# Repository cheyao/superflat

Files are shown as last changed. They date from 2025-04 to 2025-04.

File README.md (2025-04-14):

# Superflat - a ultra low profile bluetooth keyboard

A super flat PG1316 bluetooth split keyboard - The thickness is projected to be within 1cm. And the dimensions will be around  12x12cm

The design has it's custom USB port, battery protection & charging circuit and bluetooth nRF52840 integration.

The firmware that will be used will be zmk, and the projected battery life will be 2 months

[](https://hc-cdn.hel1.your-objectstorage.com/s/v3/b5915856e3878978d86f16c3d9073a392f0f9930_image.png)
[](https://hc-cdn.hel1.your-objectstorage.com/s/v3/1f7b83f37460ca8510d710ef73af309514f418d7_image.png)
[](https://hc-cdn.hel1.your-objectstorage.com/s/v3/72b54a600d9b8fe1c61734ac12d110f5b7c6d3d2_image.png)
[](https://hc-cdn.hel1.your-objectstorage.com/s/v3/e2f3d3d02bae474faccb280b3d4234a8bf3ab1c3_image.png)

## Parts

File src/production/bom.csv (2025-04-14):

Designator | Footprint | Quantity | Value | LCSC Part #
C1, C7 | 0805 | 2 | 100n | C28233
C2, C3 | 0805 | 2 | 4.7u | C1779
C5, C6 | 0805 | 2 | 1u | C28323
D1, D10, D11, D12, D13, D14, D15, D16, D17, D18, D19, D2, D20, D21, D22, D23, D24, D25, D26, D27, D28, D29, D3, D30, D4, D5, D6, D7, D8, D9 | D_SOD-123F | 30 | D | C64898
D31 | D_SMA | 1 | BSD3C051V | C151996
D32 | 0805 | 1 | LED | C2297
F1 | 1206 | 1 | 750mA | C99536
J1 | USB_C_Receptacle_HRO_TYPE-C-31-M-14 | 1 | USB_C_Receptacle_USB2.0_16P | C223907
J2 | PinHeader_1x04_P2.54mm_Vertical | 1 | Conn_01x04_Pin
J3, J5 | PinHeader_1x02_P2.54mm_Vertical | 2 | Conn_01x02_Pin
J4, J6 | PinHeader_1x05_P2.54mm_Vertical | 2 | Conn_01x05_Pin
L1, L2 | 0402 | 2 | BLM15PD121SN1D
Q1, Q2 | SOT-23 | 2 | 2N7002 | C8545
R1, R2 | 0805 | 2 | 5.1k | C27834
R10, R15 | 0805 | 2 | 100k | C149504
R11 | 0603 | 1 | 2M | C22976
R12 | 0805 | 1 | 806k | C63494
R13, R8 | 0805 | 2 | 100 | C17408
R14, R6, R9 | 0805 | 3 | 10k | C17414
R3 | 0805 | 1 | 3.9k | C17614
R4, R7 | 0805 | 2 | 1.5k | C4310
R5 | 0805 | 1 | 47k | C17713
SW1, SW10, SW11, SW12, SW13, SW14, SW15, SW16, SW17, SW18, SW19, SW2, SW20, SW21, SW22, SW23, SW24, SW25, SW26, SW27, SW28, SW29, SW3, SW30, SW4, SW5, SW6, SW7, SW8, SW9 | SW_PG1316S | 30 | SW_Push
SW31, SW33 | Slide | 2 | SW_SPDT
SW32, SW34 | SolderJumper-2_P1.3mm_Open_RoundedPad1.0x1.5mm | 2 | SW_Push
U1, U5 | nRF52840_holyiot_18010_HS_simple | 2 | nRF52840_holyiot_18010
U2 | SOT-23-6-routable | 1 | SRV05-4 | C85364
U3 | VQFN-16-1EP_3x3mm_P0.5mm_EP1.6x1.6mm | 1 | BQ24075RGT | C15464
U4 | SOT-23-3 | 1 | XC6206PxxxMR

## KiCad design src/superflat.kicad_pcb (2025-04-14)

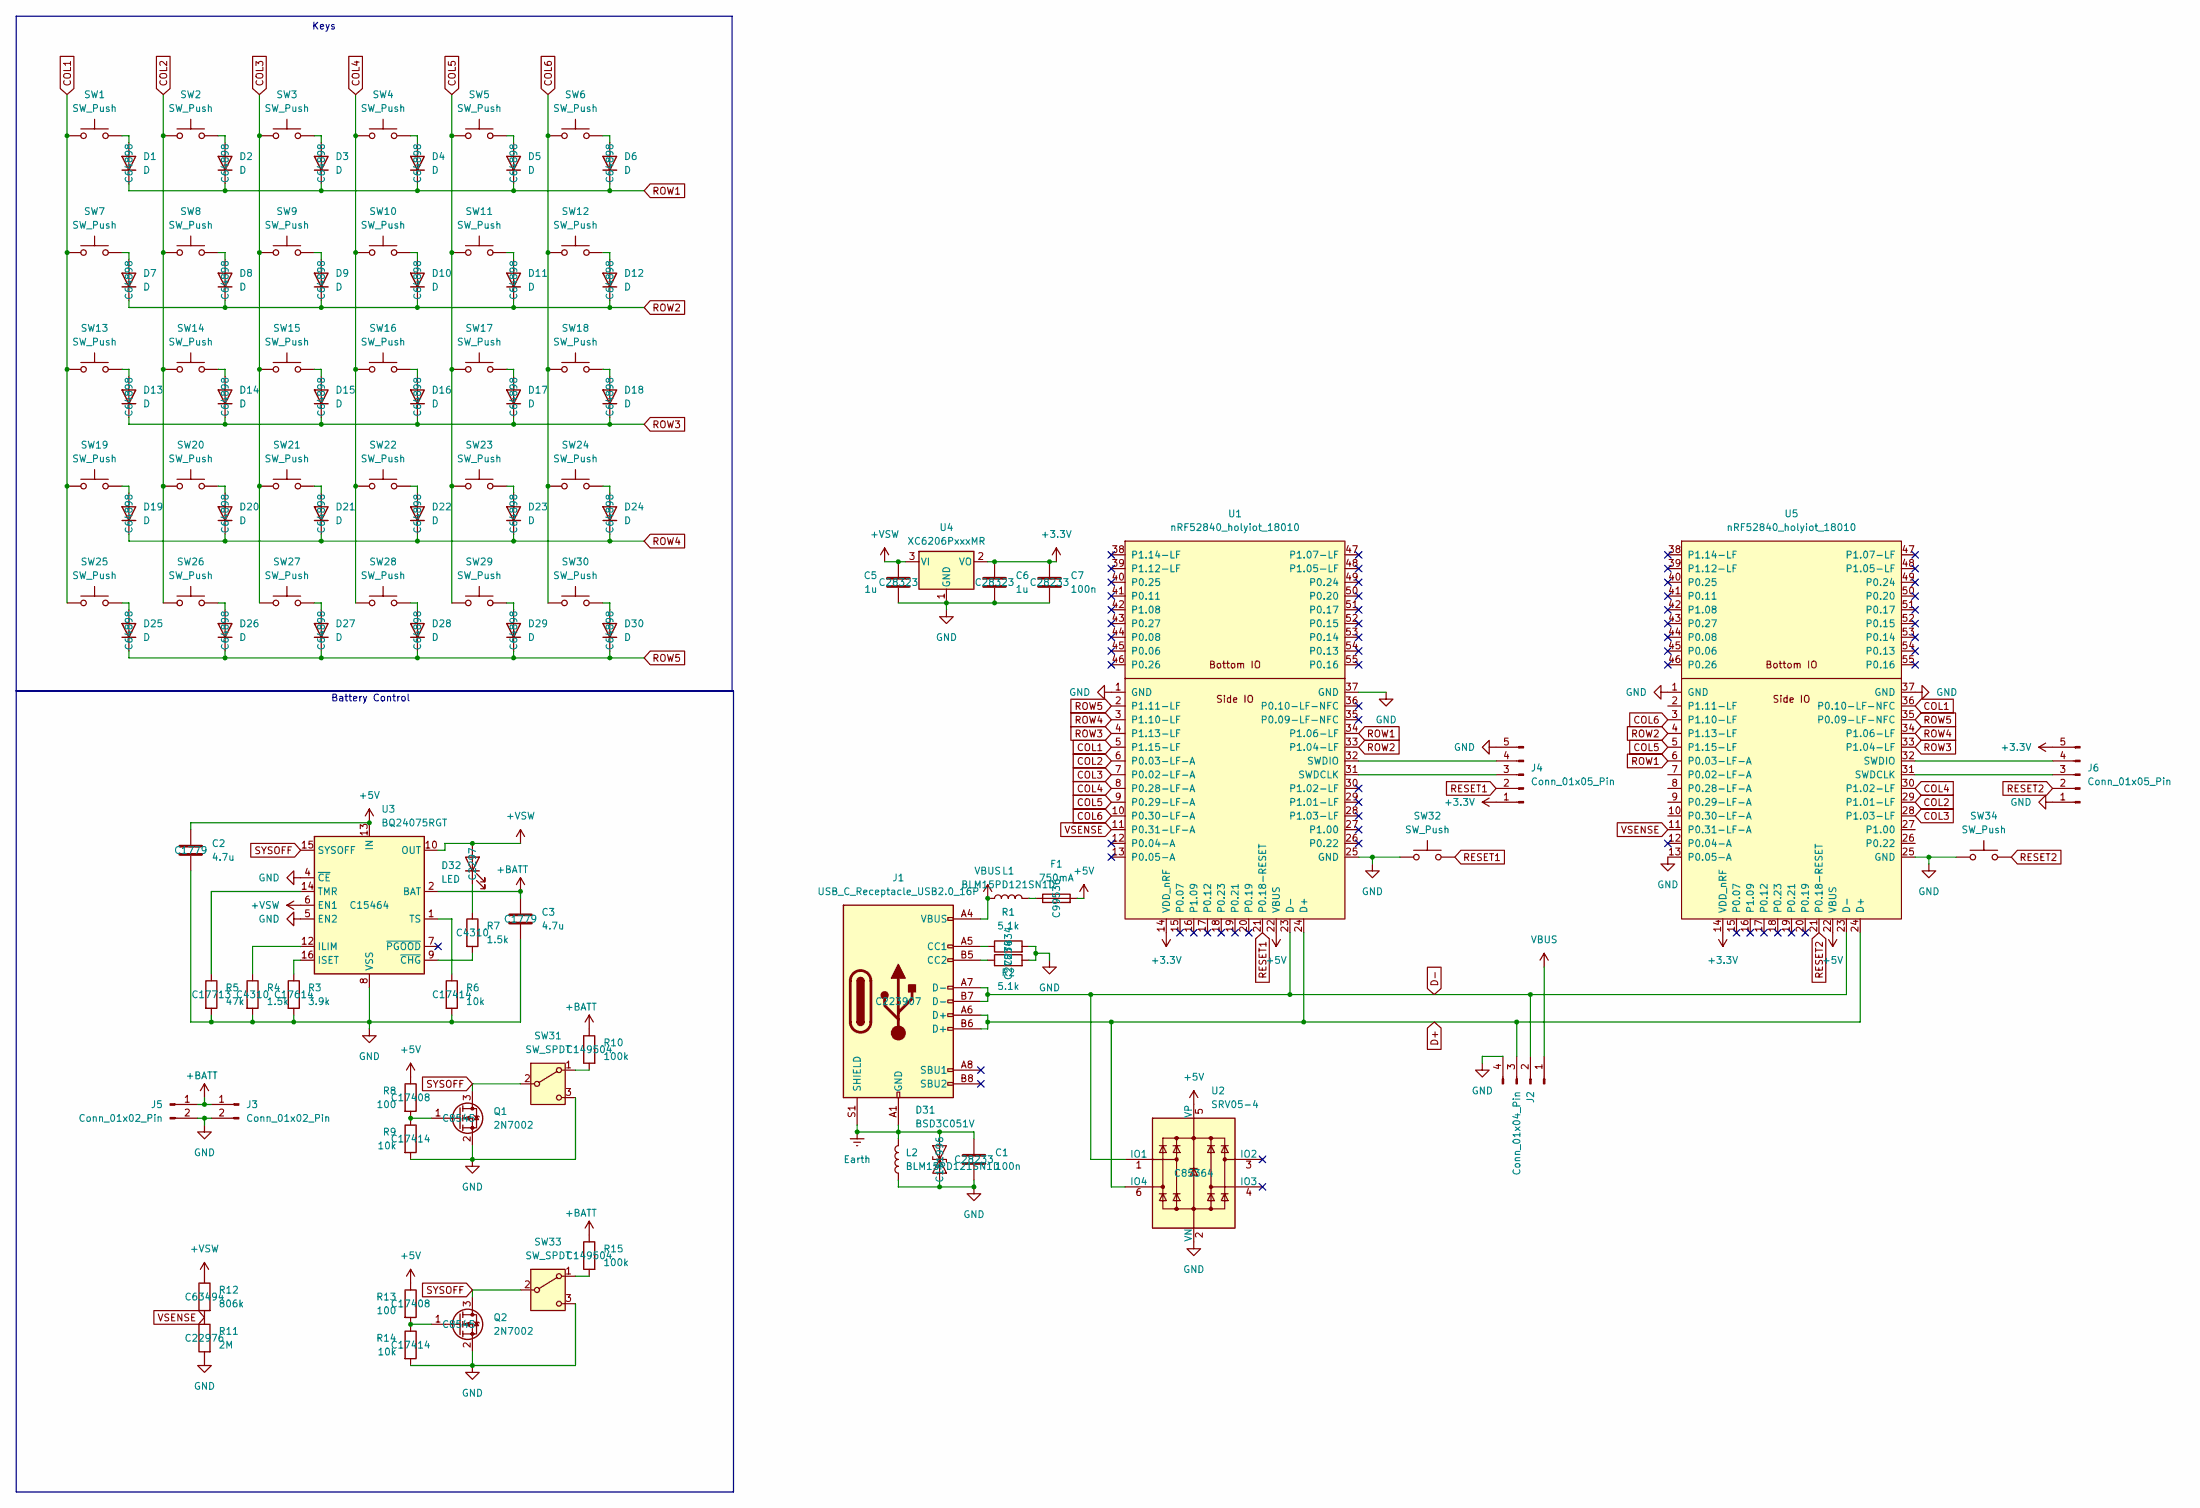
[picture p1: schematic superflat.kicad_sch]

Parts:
C1, C7: 100n; C_0805_2012Metric_Pad1.18x1.45mm_HandSolder; LCSC C28233
C2, C3: 4.7u; C_0805_2012Metric_Pad1.18x1.45mm_HandSolder; LCSC C1779
C5, C6: 1u; C_0805_2012Metric_Pad1.18x1.45mm_HandSolder; LCSC C28323
D1, D2, D3, D4, D5, D6, D7, D8, D9, D10, D11, D12, D13, D14, D15, D16, D17, D18, D19, D20, D21, D22, D23, D24, D25, D26, D27, D28, D29, D30: D; D_SOD-123F; LCSC C64898
D31: BSD3C051V; D_SMA; LCSC C151996
D32: LED; LED_0805_2012Metric_Pad1.15x1.40mm_HandSolder; LCSC C2297
F1: 750mA; Fuse_1206_3216Metric_Pad1.42x1.75mm_HandSolder; LCSC C99536
J1: USB_C_Receptacle_USB2.0_16P; USB_C_Receptacle_HRO_TYPE-C-31-M-14; LCSC C223907
J2: Conn_01x04_Pin; PinHeader_1x04_P2.54mm_Vertical
J3, J5: Conn_01x02_Pin; PinHeader_1x02_P2.54mm_Vertical
J4, J6: Conn_01x05_Pin; PinHeader_1x05_P2.54mm_Vertical
L1, L2: BLM15PD121SN1D; L_0402_1005Metric_Pad0.77x0.64mm_HandSolder
Q1, Q2: 2N7002; SOT-23; LCSC C8545
R1, R2: 5.1k; R_0805_2012Metric_Pad1.20x1.40mm_HandSolder; LCSC C27834
R3: 3.9k; R_0805_2012Metric_Pad1.20x1.40mm_HandSolder; LCSC C17614
R4, R7: 1.5k; R_0805_2012Metric_Pad1.20x1.40mm_HandSolder; LCSC C4310
R5: 47k; R_0805_2012Metric_Pad1.20x1.40mm_HandSolder; LCSC C17713
R6, R9, R14: 10k; R_0805_2012Metric_Pad1.20x1.40mm_HandSolder; LCSC C17414
R8, R13: 100; R_0805_2012Metric_Pad1.20x1.40mm_HandSolder; LCSC C17408
R10, R15: 100k; R_0805_2012Metric_Pad1.20x1.40mm_HandSolder; LCSC C149504
R11: 2M; R_0603_1608Metric_Pad0.98x0.95mm_HandSolder; LCSC C22976
R12: 806k; R_0805_2012Metric_Pad1.20x1.40mm_HandSolder; LCSC C63494
SW1, SW2, SW3, SW4, SW5, SW6, SW7, SW8, SW9, SW10, SW11, SW12, SW13, SW14, SW15, SW16, SW17, SW18, SW19, SW20, SW21, SW22, SW23, SW24, SW25, SW26, SW27, SW28, SW29, SW30: SW_Push; SW_PG1316S
SW31, SW33: SW_SPDT; Slide
SW32, SW34: SW_Push; SolderJumper-2_P1.3mm_Open_RoundedPad1.0x1.5mm
U1, U5: nRF52840_holyiot_18010; nRF52840_holyiot_18010_HS_simple
U2: SRV05-4; SOT-23-6-routable; LCSC C85364
U3: BQ24075RGT; VQFN-16-1EP_3x3mm_P0.5mm_EP1.6x1.6mm; LCSC C15464
U4: XC6206PxxxMR; SOT-23-3

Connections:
+3.3V: C6.1, C7.1, J4.1, J6.5, U1.14 (VDD_nRF), U4.2 (VO), U5.14 (VDD_nRF)
+5V: C2.1, F1.2, R8.1, R13.1, U1.22 (VBUS), U2.5 (VP), U3.13 (IN), U5.22 (VBUS)
+BATT: C3.1, J3.1, J5.1, R10.1, R15.1, U3.2 (BAT), U3.3 (BAT)
+VSW: C5.1, D32.2 (A), R12.1, U3.6 (EN1), U3.10 (OUT), U3.11 (OUT), U4.3 (VI)
COL1: SW1.1, SW7.1, SW13.1, SW19.1, SW25.1, U1.5 (P1.15-LF), U5.36 (P0.10-LF-NFC)
COL2: SW2.1, SW8.1, SW14.1, SW20.1, SW26.1, U1.6 (P0.03-LF-A), U5.29 (P1.01-LF)
COL3: SW3.1, SW9.1, SW15.1, SW21.1, SW27.1, U1.7 (P0.02-LF-A), U5.28 (P1.03-LF)
COL4: SW4.1, SW10.1, SW16.1, SW22.1, SW28.1, U1.8 (P0.28-LF-A), U5.30 (P1.02-LF)
COL5: SW5.1, SW11.1, SW17.1, SW23.1, SW29.1, U1.9 (P0.29-LF-A), U5.5 (P1.15-LF)
COL6: SW6.1, SW12.1, SW18.1, SW24.1, SW30.1, U1.10 (P0.30-LF-A), U5.3 (P1.10-LF)
D+: J1.A6 (D+), J1.B6 (D+), J2.3, SW4.MP, U1.24 (D+), U2.6 (IO4), U5.24 (D+)
D-: J1.A7 (D-), J1.B7 (D-), J2.2, U1.23 (D-), U2.1 (IO1), U5.23 (D-)
Earth: C1.1, D31.2 (A2), J1.A1 (GND), J1.A12 (GND), J1.B1 (GND), J1.B12 (GND), J1.S1 (SHIELD), L2.2
GND: C1.2, C2.2, C3.2, C5.2, C6.2, C7.2, D31.1 (A1), J2.4, J3.2, J4.5, J5.2, J6.1, L2.1, Q1.2 (S), Q2.2 (S), R1.2, R2.2, R3.2, R4.2, R5.2, R6.2, R9.2, R11.2, R14.2, SW5.MP, SW6.MP, SW7.MP, SW31.3 (C), SW32.1, SW33.3 (C), SW34.1, U1.1 (GND), U1.25 (GND), U1.37 (GND), U2.2 (VN), U3.4 (~CE), U3.5 (EN2), U3.8 (VSS), U3.17 (VSS), U4.1 (GND), U5.1 (GND), U5.13 (P0.05-A), U5.25 (GND), U5.37 (GND)
unnamed: D1.2 (A), SW1.2
unnamed: D2.2 (A), SW2.2
unnamed: D3.2 (A), SW3.2
unnamed: D4.2 (A), SW4.2
unnamed: D5.2 (A), SW5.2
unnamed: D6.2 (A), SW6.2
unnamed: D7.2 (A), SW7.2
unnamed: D8.2 (A), SW8.2
unnamed: D9.2 (A), SW9.2
unnamed: D10.2 (A), SW10.2
unnamed: D11.2 (A), SW11.2
unnamed: D12.2 (A), SW12.2
unnamed: D13.2 (A), SW13.2
unnamed: D14.2 (A), SW14.2
unnamed: D15.2 (A), SW15.2
unnamed: D16.2 (A), SW16.2
unnamed: D17.2 (A), SW17.2
unnamed: D18.2 (A), SW18.2
unnamed: D19.2 (A), SW19.2
unnamed: D20.2 (A), SW20.2
unnamed: D21.2 (A), SW21.2
unnamed: D22.2 (A), SW22.2
unnamed: D23.2 (A), SW23.2
unnamed: D24.2 (A), SW24.2
unnamed: D25.2 (A), SW25.2
unnamed: D26.2 (A), SW26.2
unnamed: D27.2 (A), SW27.2
unnamed: D28.2 (A), SW28.2
unnamed: D29.2 (A), SW29.2
unnamed: D30.2 (A), SW30.2
unnamed: D32.1 (K), R7.1
unnamed: F1.1, L1.2
unnamed: J1.A5 (CC1), R1.1
unnamed: J1.B5 (CC2), R2.1
unnamed: J4.3, U1.31 (SWDCLK)
unnamed: J4.4, U1.32 (SWDIO)
unnamed: J6.3, U5.31 (SWDCLK)
unnamed: J6.4, U5.32 (SWDIO)
unnamed: Q1.1 (G), R8.2, R9.1
unnamed: Q2.1 (G), R13.2, R14.1
unnamed: R10.2, SW31.1 (A)
unnamed: R15.2, SW33.1 (A)
unnamed: R4.1, U3.12 (ILIM)
unnamed: R3.1, U3.16 (ISET)
unnamed: R5.1, U3.14 (TMR)
unnamed: R6.1, U3.1 (TS)
unnamed: R7.2, U3.9 (~CHG)
RESET1: J4.2, SW32.2, U1.21 (P0.18-RESET)
RESET2: J6.2, SW34.2, U5.21 (P0.18-RESET)
ROW1: D1.1 (K), D2.1 (K), D3.1 (K), D4.1 (K), D5.1 (K), D6.1 (K), U1.34 (P1.06-LF), U5.6 (P0.03-LF-A)
ROW2: D7.1 (K), D8.1 (K), D9.1 (K), D10.1 (K), D11.1 (K), D12.1 (K), U1.33 (P1.04-LF), U5.4 (P1.13-LF)
ROW3: D13.1 (K), D14.1 (K), D15.1 (K), D16.1 (K), D17.1 (K), D18.1 (K), U1.4 (P1.13-LF), U5.33 (P1.04-LF)
ROW4: D19.1 (K), D20.1 (K), D21.1 (K), D22.1 (K), D23.1 (K), D24.1 (K), U1.3 (P1.10-LF), U5.34 (P1.06-LF)
ROW5: D25.1 (K), D26.1 (K), D27.1 (K), D28.1 (K), D29.1 (K), D30.1 (K), U1.2 (P1.11-LF), U5.35 (P0.09-LF-NFC)
SYSOFF: Q1.3 (D), Q2.3 (D), SW31.2 (B), SW33.2 (B), U3.15 (SYSOFF)
VBUS: J1.A4 (VBUS), J1.A9 (VBUS), J1.B4 (VBUS), J1.B9 (VBUS), J2.1, L1.1
VSENSE: R11.1, R12.2, U1.11 (P0.31-LF-A), U5.11 (P0.31-LF-A)

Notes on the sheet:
Battery Control
Keys

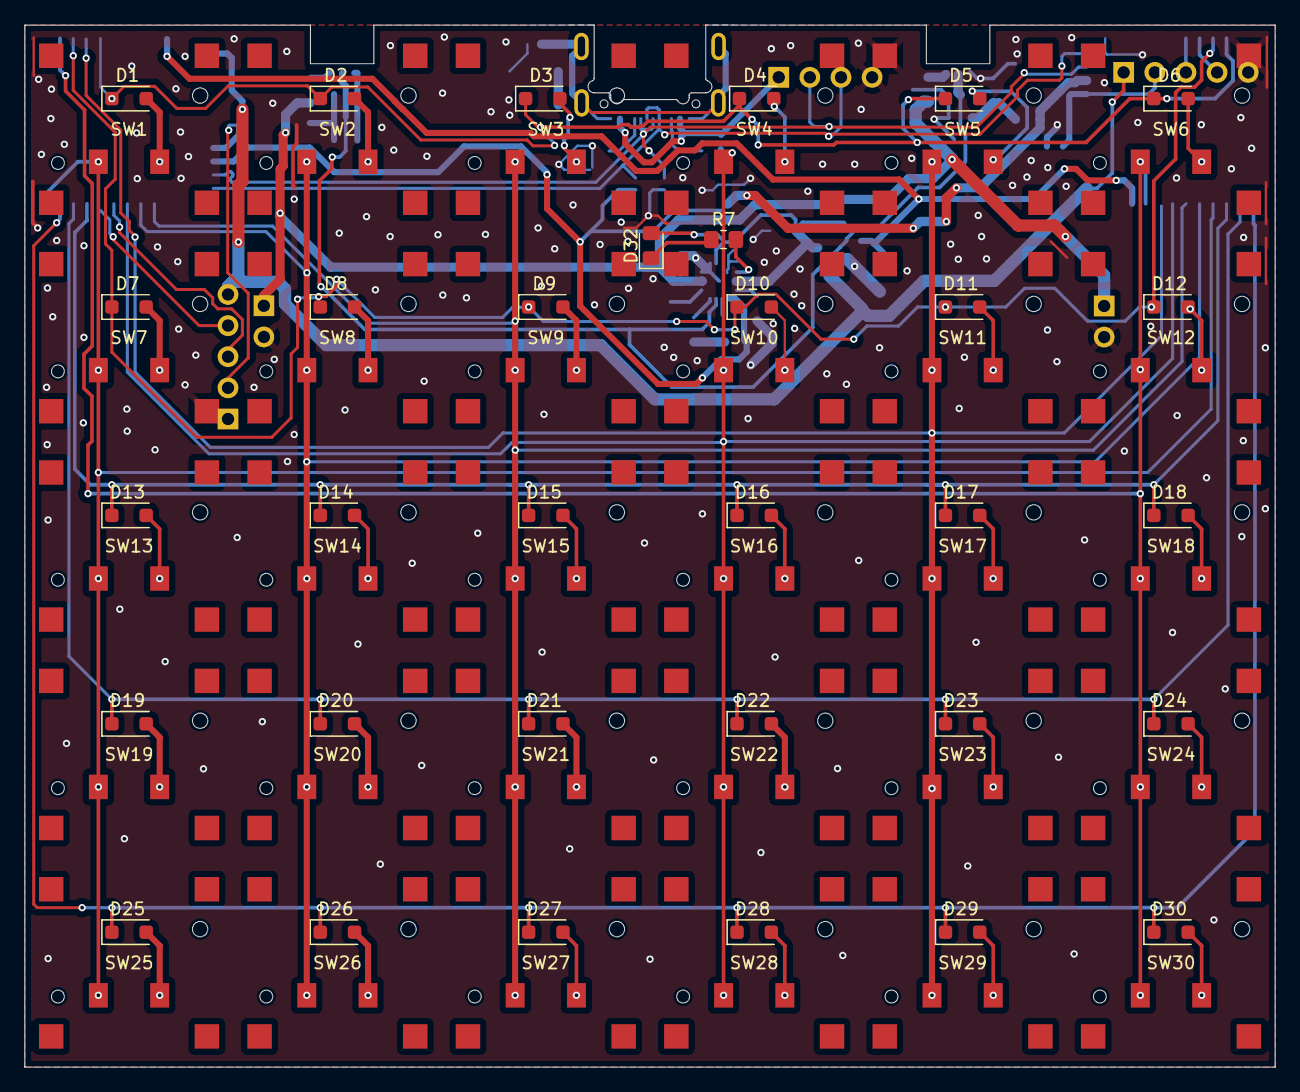
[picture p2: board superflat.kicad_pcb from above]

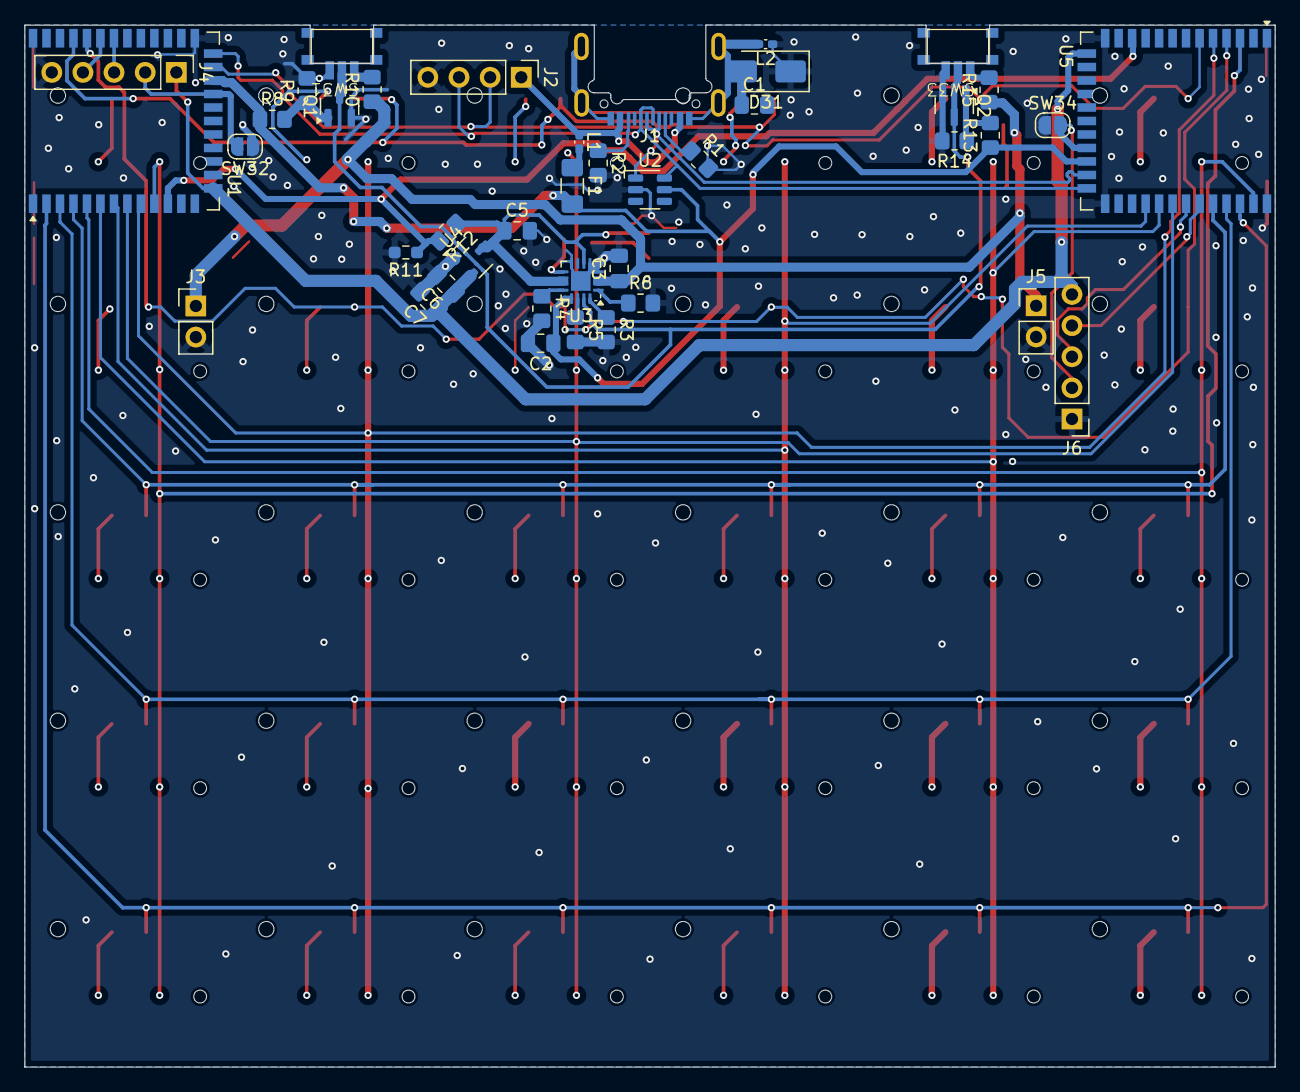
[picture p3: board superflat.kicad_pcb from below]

Board: 2 copper layers, 102.0 x 85.0 mm, 103 parts (41 on the bottom side), 71 nets.

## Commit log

2025-04-13 V2 done!
    [superflat.kicad_pcb, superflat.kicad_sch]
2025-04-14 Final cleanup
    [bom.csv, designators.csv, positions.csv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]
